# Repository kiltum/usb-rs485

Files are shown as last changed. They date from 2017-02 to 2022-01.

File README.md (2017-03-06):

# USB to RS-485 adapter

Here is a small board for my home development purposes.

- Able to download firmware through USB or ST-Link/V2 from discovery boards
- Can act as USB to rs-485 adapter
- Can act as USB/RS-485 thermometer
- Can show one digit (or break it to 8 leds) for some purposes.
- Can be powered from USB or from RS-485 bus. 

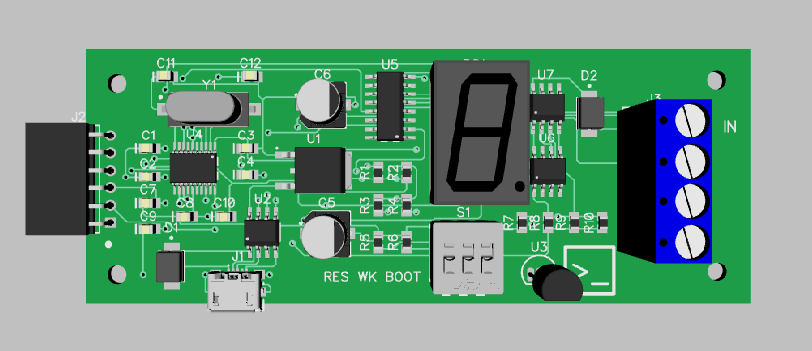
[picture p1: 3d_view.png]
How it should look

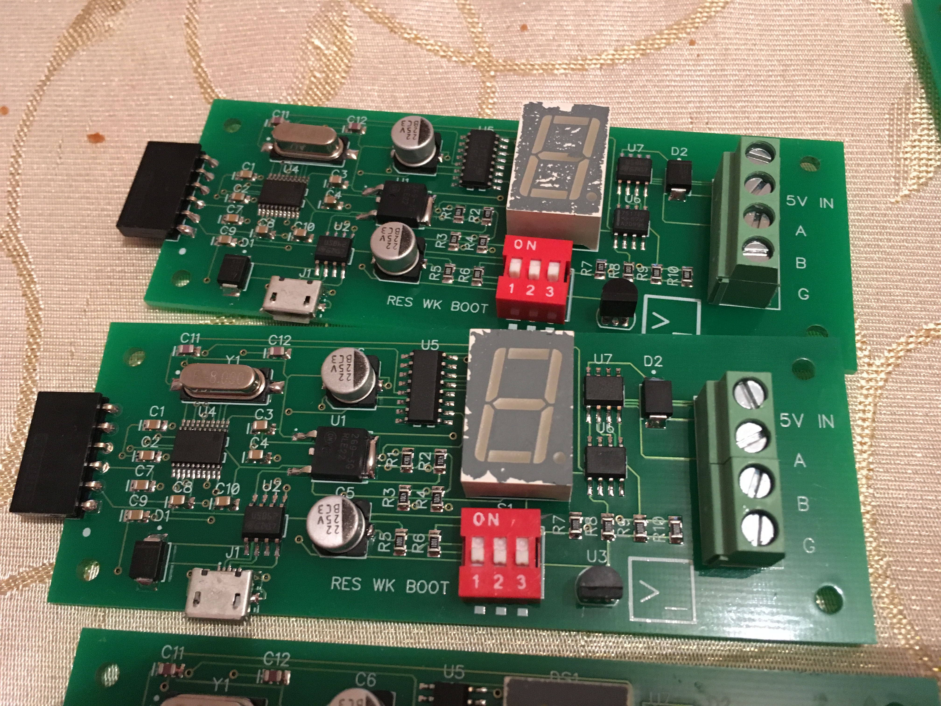
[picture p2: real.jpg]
How it look in real


# Current status

- (DONE) Create schematics
- (DONE) Create board 
- (DONE) Order boards
- (DONE) Order materials
- (DONE) Assemble board
- (DONE) To boast (you can look at video.m4v)
- (IN PROG) Write firmware. Take a piece of code. I use this board for internal purposes, so all in your hands

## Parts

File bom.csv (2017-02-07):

# | RefDes | Name | Value | Quantity | Total for 10 | Ordered?
1 | C1, C2, C7, C9 | GRM216R71H103K | 0.01uF | 4 | 40 | x
2 | C3, C4, C8, C10 | GRM21BR71H104K | 0.1uF | 4 | 40 | x
3 | C5, C6 | B41121A5226M000 | 22uF | 2 | 20 | x
4 | C11, C12 | GRM2195C2D220J | 22pF | 2 | 20 | x
5 | D1, D2 | 10BQ060 |  | 2 | 20 | x
6 | DS1 | SA56-11EWA |  | 1 | 10 | x
7 | J1 | 47346-0001 |  | 1 | 10 | x
8 | J2 | PBS-6R (DS-1024-1x6-R) |  | 1 | 10 | x
9 | J3, J4 | KLS2-126-5.00-02P-4S (DG126-5.0-02P-14) |  | 2 | 20 | x
10 | R1, R2, R3, R4 | 4.7k (0805) | 4.7k | 4 | 40 | x
11 | R5, R6, R7, R8, R9, R10 | 1k (0805) | 1k | 6 | 60 | x
12 | S1 | DS1040-03RN |  | 1 | 10 | x
13 | U1 | MC33269DT-3.3G |  | 1 | 10 | x
14 | U2, U7 | USB6B1RL | USB6B1RL | 2 | 20 | x
15 | U3 | DS18B20 |  | 1 | 10 | x
16 | U4 | STM32F042F6P6 |  | 1 | 10 | x
17 | U5 | STP08DP05MTR |  | 1 | 10 | x
18 | U6 | SN75176BD |  | 1 | 10 | x
19 | Y1 | HC-49SM | 8MHz | 1 | 10 | x
 |  |  |  | 38 | 380

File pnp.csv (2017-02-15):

RefDes | Name | X (in) | Y (in) | Side | Rotate | Value
C1 | GRM216R71H103K | 0.362 | 0.887 | Top | 0 | 0.01uF
C2 | GRM216R71H103K | 0.362 | 0.725 | Top | 0 | 0.01uF
C3 | GRM21BR71H104K | 0.925 | 0.887 | Top | 0 | 0.1uF
C4 | GRM21BR71H104K | 0.925 | 0.738 | Top | 0 | 0.1uF
C5 | B41121A5226M000 | 1.384 | 0.4 | Top | 0 | 22uF
C6 | B41121A5226M000 | 1.359 | 1.138 | Top | 0 | 22uF
C7 | GRM216R71H103K | 0.362 | 0.575 | Top | 0 | 0.01uF
C8 | GRM21BR71H104K | 0.575 | 0.5 | Top | 0 | 0.1uF
C9 | GRM216R71H103K | 0.362 | 0.425 | Top | 0 | 0.01uF
C10 | GRM21BR71H104K | 0.8 | 0.5 | Top | 0 | 0.1uF
C11 | GRM2195C2D220J | 0.462 | 1.3 | Top | 0 | 22pF
C12 | GRM2195C2D220J | 0.95 | 1.3 | Top | 0 | 22pF
D1 | 10BQ060 | 0.487 | 0.213 | Top | 270
D2 | 10BQ060 | 2.887 | 1.088 | Top | 270
DS1 | SA56-11EWA | 2.225 | 0.95 | Top | 90
J1 | 47346-0001 | 0.867 | 0.113 | Top | 0
J2 | PBS-6R (DS-1024-1x6-R) | 0.138 | 0.712 | Top | 90
J3 | KLS2-126-5.00-02P-4S (DG126-5.0-02P-14) | 3.238 | 0.903 | Top | 270
J4 | KLS2-126-5.00-02P-4S (DG126-5.0-02P-14) | 3.238 | 0.509 | Top | 270
R1 | 4.7k (0805) | 1.675 | 0.75 | Top | 270 | 4.7k
R2 | 4.7k (0805) | 1.838 | 0.75 | Top | 90 | 4.7k
R3 | 4.7k (0805) | 1.675 | 0.562 | Top | 90 | 4.7k
R4 | 4.7k (0805) | 1.838 | 0.562 | Top | 90 | 4.7k
R5 | 1k (0805) | 1.675 | 0.35 | Top | 270 | 1k
R6 | 1k (0805) | 1.838 | 0.35 | Top | 270 | 1k
R7 | 1k (0805) | 2.5 | 0.462 | Top | 90 | 1k
R8 | 1k (0805) | 2.65 | 0.462 | Top | 90 | 1k
R9 | 1k (0805) | 2.8 | 0.462 | Top | 90 | 1k
R10 | 1k (0805) | 2.962 | 0.462 | Top | 90 | 1k
S1 | DS1040-03RN | 2.162 | 0.287 | Top | 90
U1 | MC33269DT-3.3G | 1.303 | 0.76 | Top | 0
U2 | USB6B1RL | 1.013 | 0.406 | Top | 90 | USB6B1RL
U3 | DS18B20 | 2.6 | 0.162 | Top | 0
U4 | STM32F042F6P6 | 0.622 | 0.773 | Top | 270
U5 | STP08DP05MTR | 1.744 | 1.125 | Top | 180
U6 | SN75176BD | 2.643 | 0.755 | Top | 90
U7 | USB6B1RL | 2.638 | 1.119 | Top | 90 | USB6B1RL
Y1 | HC-49SM | 0.703 | 1.113 | Top | 0 | 8MHz

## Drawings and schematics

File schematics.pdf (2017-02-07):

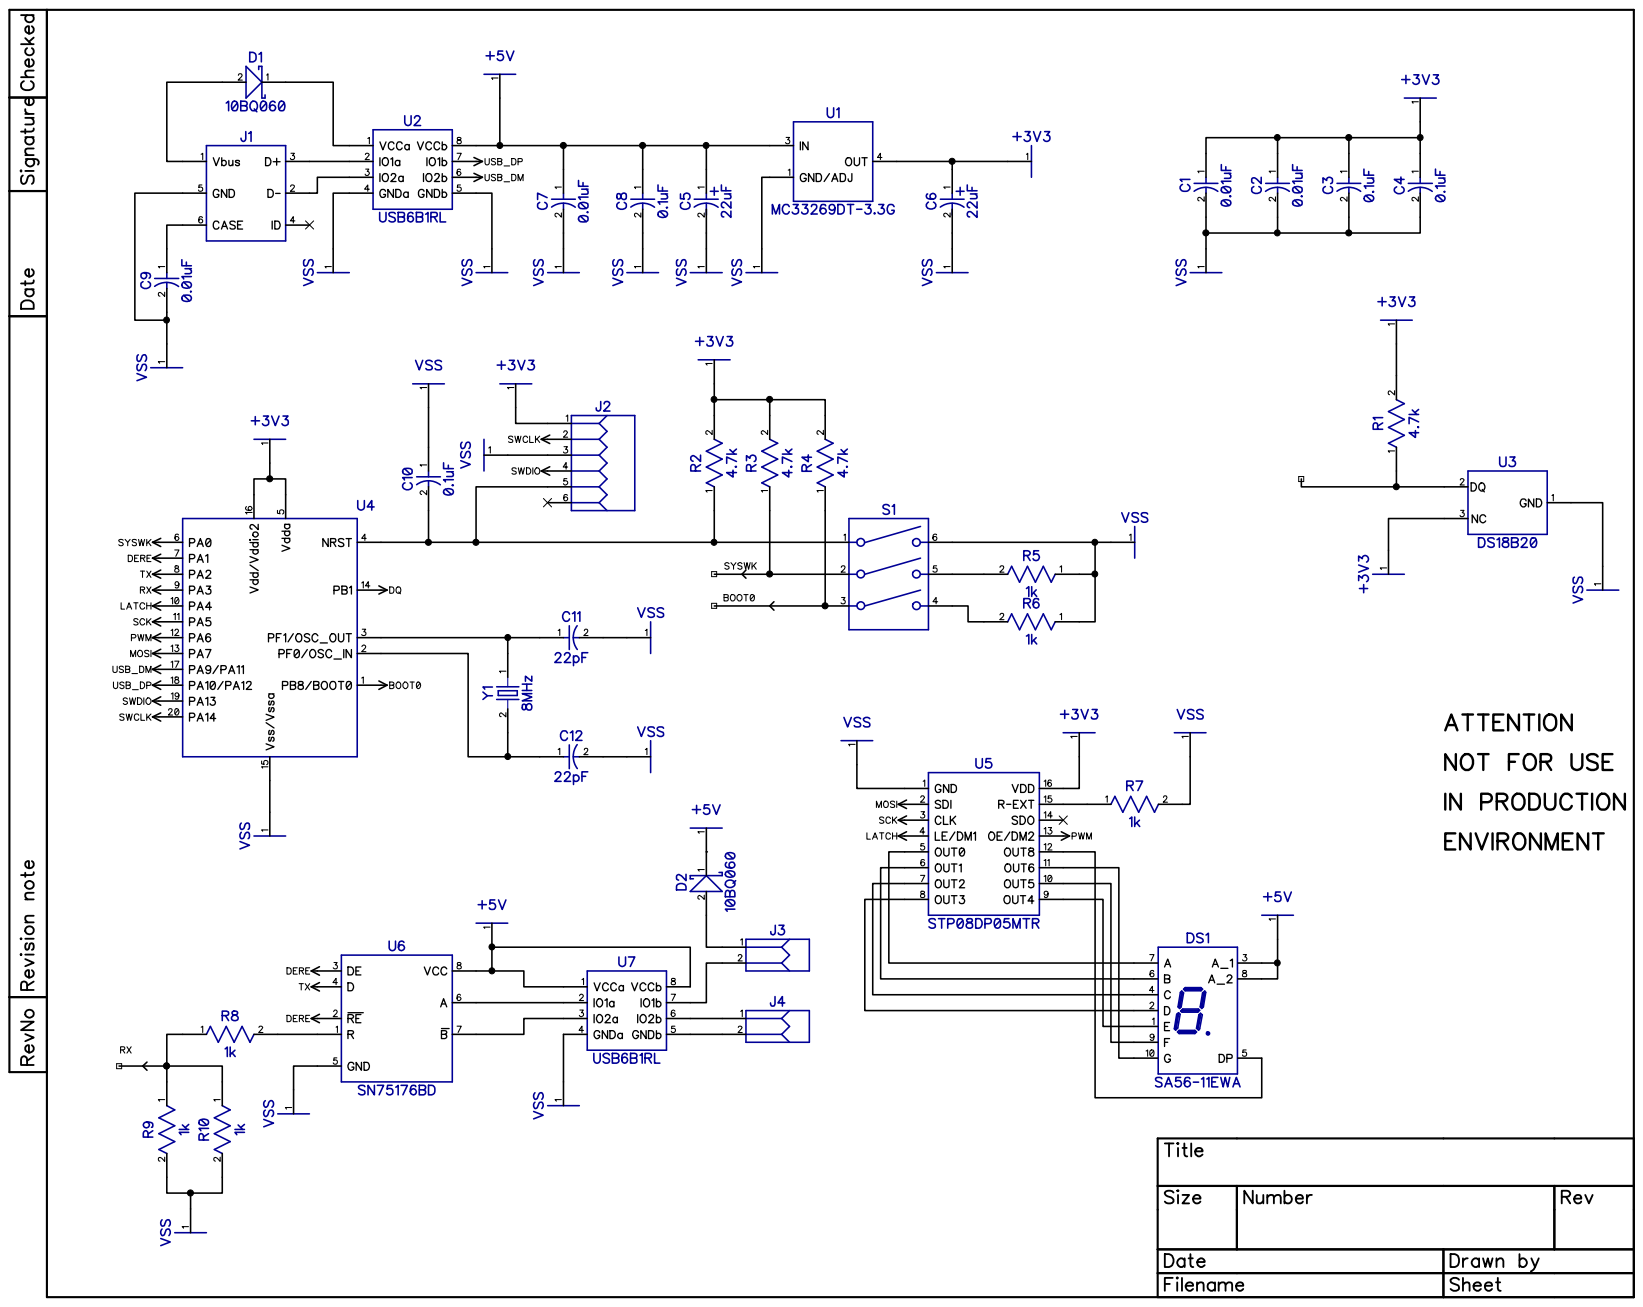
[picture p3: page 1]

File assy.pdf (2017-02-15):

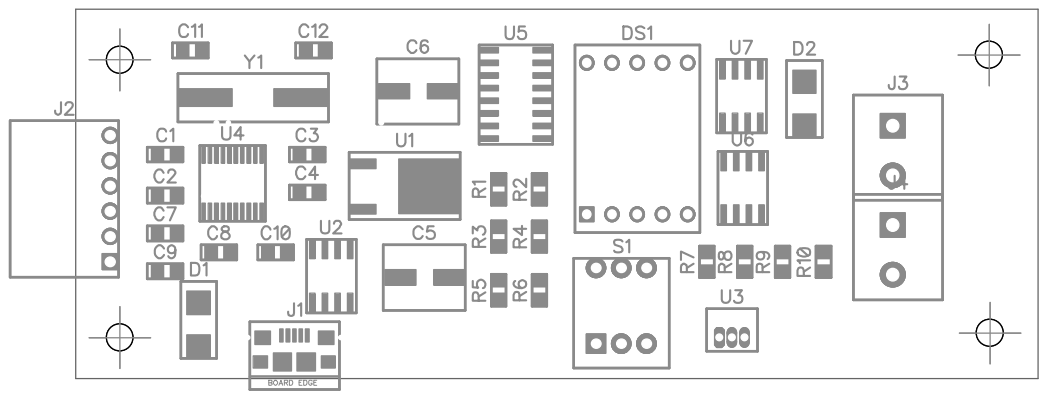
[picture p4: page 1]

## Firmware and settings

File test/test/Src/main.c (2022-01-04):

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
/* Includes ------------------------------------------------------------------*/
#include "main.h"
#include "spi.h"
#include "tim.h"
#include "usb_device.h"
#include "gpio.h"


/* USER CODE BEGIN PV */

/* USER CODE END PV */

void SystemClock_Config(void);
/* USER CODE BEGIN PFP */

/* USER CODE END PFP */

/**
  * @brief  The application entry point.
  * @retval int
  */
int main(void)
{
  /* MCU Configuration--------------------------------------------------------*/

  /* Reset of all peripherals, Initializes the Flash interface and the Systick. */
  HAL_Init();

  /* Configure the system clock */
  SystemClock_Config();

  /* Initialize all configured peripherals */
  MX_GPIO_Init();
  MX_SPI1_Init();
  MX_TIM3_Init();
  MX_TIM17_Init();
  MX_USB_DEVICE_Init();
  /* USER CODE BEGIN 2 */
#define bin(a) ((( (a/10000000*128) + \
(((a/1000000)&1)*64) + \
(((a/100000)&1)*32) + \
(((a/10000)&1)*16) + \
(((a/1000)&1)*8) + \
(((a/100)&1)*4) + \
(((a/10)&1)*2) + \
(a&1)) * (a/10000000)) + \
(( ((a/262144)*64) + \
(((a/32768)&1)*32) + \
(((a/4096)&1)*16) + \
(((a/512)&1)*8) + \
(((a/64)&1)*4) + \
(((a/8)&1)*2) + \
(a&1)) * (1-(a/10000000))))

  /* Infinite loop */
  uint8_t buf[11];
  buf[0]=bin(00111111);
  buf[1]=bin(00000110);
  buf[2]=bin(01011011);
  buf[3]=bin(01001111);
  buf[4]=bin(01100110);
  buf[5]=bin(01101101);
  buf[6]=bin(01111101);
  buf[7]=bin(00000111);
  buf[8]=bin(01111111);
  buf[9]=bin(01101111);
  buf[10]=0;
  uint8_t n,s;
  n=0;
  HAL_GPIO_WritePin(GPIOA, GPIO_PIN_6, GPIO_PIN_RESET);
  /* USER CODE END 2 */

  /* Infinite loop */
  /* USER CODE BEGIN WHILE */
  while (1)
  {
    /* USER CODE END WHILE */

    /* USER CODE BEGIN 3 */
    s = buf[n];
    HAL_SPI_Transmit(&hspi1, &s,1, 0x1000);
    HAL_GPIO_WritePin(GPIOA, GPIO_PIN_4, GPIO_PIN_SET);
    HAL_Delay(1);
    HAL_GPIO_WritePin(GPIOA, GPIO_PIN_4, GPIO_PIN_RESET);
    HAL_Delay(500);
    n++;
    if(n>9) n=0;

  }
  /* USER CODE END 3 */
}

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
/**
  * @brief  Period elapsed callback in non blocking mode
  * @note   This function is called  when TIM14 interrupt took place, inside
  * HAL_TIM_IRQHandler(). It makes a direct call to HAL_IncTick() to increment
  * a global variable "uwTick" used as application time base.
  * @param  htim : TIM handle
  * @retval None
  */
void HAL_TIM_PeriodElapsedCallback(TIM_HandleTypeDef *htim)
{
  if (htim->Instance == TIM14) {
    HAL_IncTick();
  }
}

/**
  * @brief  This function is executed in case of error occurrence.
  * @retval None
  */
void Error_Handler(void)
{
  /* USER CODE BEGIN Error_Handler_Debug */
  /* User can add his own implementation to report the HAL error return state */
  __disable_irq();
  while (1)
  {
  }
  /* USER CODE END Error_Handler_Debug */
}

#ifdef  USE_FULL_ASSERT
/**
  * @brief  Reports the name of the source file and the source line number
  *         where the assert_param error has occurred.
  * @param  file: pointer to the source file name
  * @param  line: assert_param error line source number
  * @retval None
  */
void assert_failed(uint8_t *file, uint32_t line)
{
  /* USER CODE BEGIN 6 */
  /* User can add his own implementation to report the file name and line number,
    ex: printf("Wrong parameters value: file %s on line %d\r\n", file, line) */
  /* USER CODE END 6 */
}
#endif /* USE_FULL_ASSERT */

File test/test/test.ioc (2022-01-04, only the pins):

Mcu.UserName=STM32F042F6Px
PA0.Signal=GPIO_Input
PA11.Signal=USB_DM
PA12.Signal=USB_DP
PA13.Signal=SYS_SWDIO
PA14.Signal=SYS_SWCLK
PA4.GPIO_Label=SPI_LATCH
PA4.Signal=GPIO_Output
PA5.Signal=SPI1_SCK
PA6.GPIO_Label=SPI_DE
PA6.Signal=GPIO_Output
PA7.Signal=SPI1_MOSI
PB1.Signal=GPIO_Input
PF0-OSC_IN.Signal=RCC_OSC_IN
PF1-OSC_OUT.Signal=RCC_OSC_OUT

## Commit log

2017-02-07 First Release
    [BoardOutline.gbr, Bottom.gbr, BottomAssy.gbr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]
2017-02-07 Add BOM
    [bom.csv]
2017-02-07 Pinout sync to board
2017-02-07 FIxed BOM
    [bom.csv]
2017-02-07 I hate excel
    change delimeter
    [bom.csv]
2017-02-07 Order All
    [bom.csv]
2017-02-07 Fix chip overlapping
    [BoardOutline.gbr, Bottom.gbr, BottomAssy.gbr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]
2017-02-07 Fix gerber
2017-02-15 Assy boards
    [pnp.csv]
2017-02-25 Digit show thru SPI works
2017-02-25 timer of 10mks done
2022-01-03 switch to new firmware
2022-01-03 fix count and echo
    [main.c]
2022-01-04 test done
    [result.csv]
2022-01-04 small fixes
    [result.csv]
2022-01-06 -- WIP ---
    [result.csv]

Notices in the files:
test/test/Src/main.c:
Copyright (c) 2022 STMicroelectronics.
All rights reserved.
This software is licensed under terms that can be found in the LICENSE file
